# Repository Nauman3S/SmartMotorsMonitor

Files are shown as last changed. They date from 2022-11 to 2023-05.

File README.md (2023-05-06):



<!-- PROJECT LOGO -->
<br />
<div align="center">
  <a href="https://github.com/othneildrew/Best-README-Template">
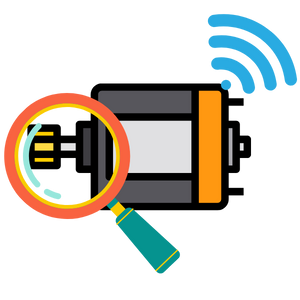
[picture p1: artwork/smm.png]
    
  </a>

  <h3 align="center">SmartMotorsMonitor</h3>

  <p align="center">
    Motors Monitoring System with different sensors.
    <br />
  </p>
</div>

---

<p align="center"> SmartMotorsMonitor
    <br> 
</p>

<!-- TABLE OF CONTENTS -->
<details>
  <summary>📝Table of Contents</summary>
  <ol>
    <li>
      <a href="#about-the-project">About The Project</a>
    </li>
    <li><a href="#getting_started">Getting Started</a></li>
    <li><a href="#circuit">Circuit</a></li>
    <li><a href="#architecture">Architecture</a></li>
    <li><a href="#usage">Usage</a></li>
    <li><a href="#webapp">WebApp</a></li>
    <li><a href="#smartphoneapp">SmartphoneApp</a></li>
    <li><a href="#built_using">Built Using</a></li>
    <li><a href="#authors">Authors</a></li>
  </ol>
</details>

<!-- ABOUT THE PROJECT -->
## 🧐 About 

This repo contains

- Firmware
- Circuit Diagram
- Detailed instructions

for Smart Motor Device Monitor.

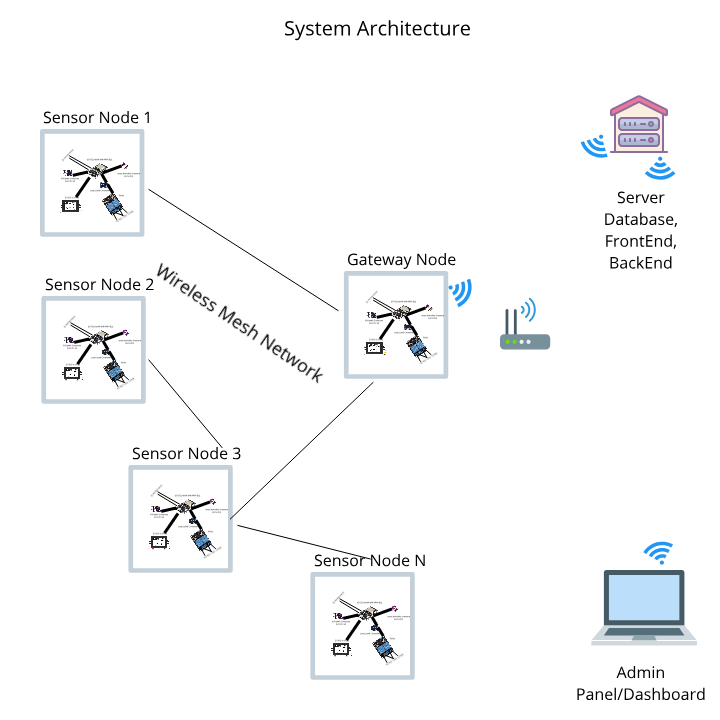
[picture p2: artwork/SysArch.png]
Architecture


<p align="right">(<a href="#readme-top">back to top</a>)</p>

## Getting Started 

These instructions will get you a copy of the project up and running on your system.

### Prerequisites

Things you need to install the FW.

```
- Arduino IDE
```

### Installing 

A step by step series that tell you how to get the Firmware and Backend running

#### ESP32 Configuration

You should have Arduino IDE Installed

  1.  Add ESP32 Board to your Arduino IDE
    1. In your Arduino IDE, go to File> Preferences
        Installing ESP32 Add-on in Arduino IDE Windows, Mac OS X, Linux open preferences
    2. Enter ```https://dl.espressif.com/dl/package_esp32_index.json``` 
        into the “Additional Board Manager URLs” field then, click the “OK” button:
        Note: if you already have the ESP32 boards URL, you can separate the URLs with a comma(each board will go to neaw line) as follows:
        ```https://dl.espressif.com/dl/package_esp32_index.json,\n http://arduino.esp8266.com/stable/package_esp8266com_index.json```

  2. Open the Boards Manager. Go to Tools > Board > Boards Manager…
  3. Search for ESP32 and press install button for the ESP32 by Espressif Systems“:
  4. That’s it. It should be installed after a few seconds.
  5.   In your Arduino sketchbook directory, create tools directory if it doesn't exist yet.
  6.  Unpack the tool into tools directory(present in libs/ESP32FS-1.0.zip) (the path will look like <home_dir>/Arduino/tools/ESP32FS/tool/esp32fs.jar).
  7.  Close and re-open the Arduino IDE.

  8.  Now copy the contents of the libs folder to the libraries directory of your Arduino
      1. If you are using windows, the libraries directory will be Documents/Arduino/libraries

##### ESP32 Node FW Uploading
  1.  Select ESP32 Dev Module from Tools->Board->ESP32
  2.  Select the correct port from Tools->Port
  3.  Open SensorNode.ino file.
  5.  Upload the Code to your ESP32 Dev Module.
  6.  Your ESP32-based SensorNode is now ready to be used.

##### ESP32 Gateway Node FW Uploading
  1.  Select ESP32 Dev Module from Tools->Board->ESP32
  2.  Select the correct port from Tools->Port
  3.  open GatewayNode.ino file,
  4.  Select Tools > ESP32 Sketch Data Upload menu item. This should start uploading the files into ESP32 flash file system.
  5.  Upload the Code to your ESP32 Dev Module.
  6.  Your ESP32-based Gateway Node is now ready to be used.

<p align="right">(<a href="#readme-top">back to top</a>)</p>

## Circuit 

### ESP32 Dev Module Pinout

Follow the pinout diagram given below to connect different components to your board.

![LoraPinout](Circuit/ESP32-Pinout.jpg)

### Circuit Diagram for Smart Joystick

Here's the complete circuit diagram of the system.

![CircuitDiagram](Circuit/Circuit_bb.png)

### Components Connections

```http
Pin connection details
```

#### HWT906-TTL - IMU

```HWT906-TTL Connections with ESP32```

** Remove the HWT906-TTL case to see the connections.

| HWT906-TTL Pins | ESP32 Dev Module Pins| 
| :--- | :--- | 
| `SCL` | `D22` |
| `SDA` | `D21` |
| `VCC` | `5V` |
| `GND` | `GND` |

#### ADS1015 - ADC

```ADS1015 Connections with ESP32```

| ADS1015 Pins | ESP32 Dev Module Pins| 
| :--- | :--- | 
| `SCL` | `D22` |
| `SDA` | `D21` |
| `VCC` | `5V` |
| `GND` | `GND` |

#### Analog Input Pins

```Analog Input Pin Connected with ADS1115```

| Analog Input Pins | ADS1115 Pins| 
| :--- | :--- | 
| `A_IN1` | `A0` |
| `A_IN2` | `A1` |

#### Digital Input Pins

```Digital Input Pin Connections with ESP32```

| Digital Input Pins | ESP32 Dev Module Pins| 
| :--- | :--- | 
| `D_IN1` | `D5` |
| `D_IN2` | `D18` |

#### 4 Channel Relay Pins

```Relay Module Pin Connections with ESP32```

| Relay Module Pins | ESP32 Dev Module Pins| 
| :--- | :--- | 
| `IN1` | `D14` |
| `IN2` | `D27` |
| `IN3` | `D26` |
| `IN4` | `D25` |
| `GND` | `GND` |
| `VCC` | `5V` |

*The relay module is connected to esp32 via Logic Level Shifter*

#### Status RGB LED

```LED Connections```

| LED Pins | ESP32 Dev Module | 
| :--- | :--- | 
| `Anode` | `33 via 220Ω resistor` |
| `Cathode` | `GND` |
*33 is also connected to the internal LED of ESP32 Dev Module*

<p align="right">(<a href="#readme-top">back to top</a>)</p>

## 🔧 Mesh Architecture 

High level architecture of the Mesh network
![arch](artwork/arch.png)

<p align="right">(<a href="#readme-top">back to top</a>)</p>

## Usage 

```diff
! Ready for testing
```
Power on your Sensor Nodes.

### Gateway Node
1.  Power on your ESP32, it will present you with an AP named ```SmartMM``` (while ```SmartMM``` can be changed in the portal)
2.  Default captive portal password `12345678AP` which can be changed in captive portal.
3.  Connect to the ESP32 access point and open the web-browser and navigate to the link ```http://SmartMM.local/_ac```. This link will work on most of the operating systems but if your operating system is not allowing to open it, you may want to check the captive portal IP Address from the serial monitor and can use that IP address inplace of the above mentioned URL.
4.  The default access IP Address is ```http://192.168.4.1/_ac```
5.  You will be presented with a main dashboard as shown below(based on your device)
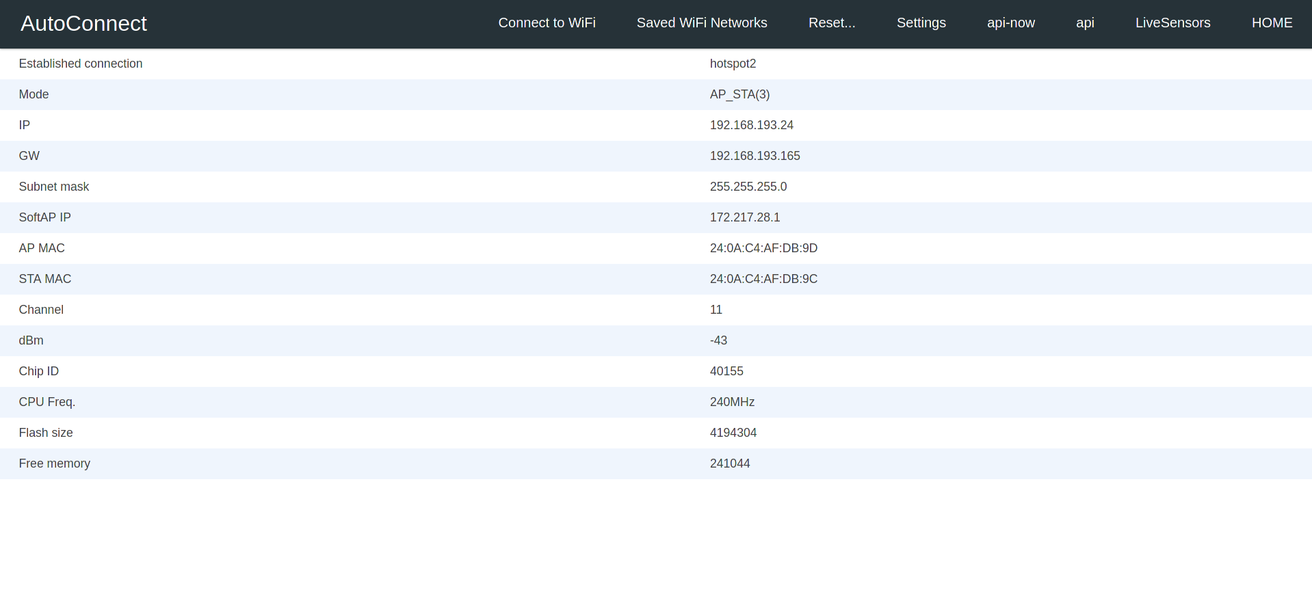
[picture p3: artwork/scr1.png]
SCR1
   

5.  Once connected to a WiFi network, you can again access the captive portal using same URL or the IP Address from the Serial monitor.
6.  The data is published to the MQTT Topic ```SmartMM/{hostname}``` while the hostname is the one which you can define in Settings page of the captive portal.

### Changing Timezone
```diff
+ Only for developers
```
1.  Open Settings tab
2.  Enter timezone string from https://en.wikipedia.org/wiki/List_of_tz_database_time_zones 'TZ database name' column.
3.  Click Save&Start

### API Endpoints and HTML URLS(for Gateway Node)

```API Endpoints```

| Endpoint | Description | 
| :--- | :--- | 
| `/api-now` | `API: live sensor readings in JSON format` |
| `/api` | `API: sensors data in JSON format` |
| `/LiveSensors` | `HTML PAGE: Live Sensor Data` |
| `/data` | `HTML PAGE: Historical Sensor Data` | 
| `/mqtt_settings` | `HTML PAGE: Settings. Default username: AP Name, Default Password: admin` | 
| `/_ac` | `HTML PAGE: Main Captive portal page` | 
| `/` | `HTML PAGE: Historical Sensor Data` | 

1.  **Connect to WiFi** tab allows searching of nearby WiFi APs and adding them to the ESP32.
   ![SCR3](artwork/scr3.png)
2.  **Saved WiFi Networks** tab allows connecting to the saved access points.
   ![SCR4](artwork/scr4.png)
3.  **Reset...** tab allows reseting of the device to factory settings.
    ![SCR5](artwork/scr5.png)
4.  **Settings** tab contains settings related to MQTT and sensors.
    ![SCR6](artwork/scr6.png)
5. **HOME** tab shows sensor data acquired live.

<p align="right">(<a href="#readme-top">back to top</a>)</p>

## Web App 
```diff
+ For future use
```
[Dashboard Link: ]()

You can access the webapp with following test acccount credentials

*   Email Address: `test@test.com`
*   Password: `test`

### Dashboard Screenshots

<p align="right">(<a href="#readme-top">back to top</a>)</p>

## Smartphone App 
```diff
+ For future use
```
[Smartphone App Link: ]()

You can access the Smartphone app with following test acccount credentials

*   Email Address: `test@test.com`
*   Password: `test`

### Smartphone App Screenshots

```diff
+ For future use.
```

<p align="right">(<a href="#readme-top">back to top</a>)</p>

## List of Components 
```diff
+ For future use; not a comprehensive list
```
Following components are used to make this project

1.  [ESP32 Dev Kit Module](https://www.amazon.ca/Robojax-Development-Bluetooth-Ultra-Low-Consumption/dp/B07PWGT83P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)

2. [Micro USB Cable](https://www.amazon.com/Android-Charger-sweguard-Charging-Phone-Grey/dp/B09MT18H3J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)

3. [Compass-IMU9250](https://www.amazon.ca/MPU-9250-MPU9250-Acceleration-Gyroscope-Compass/dp/B07T8J3WCX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)

4. [ADS1015](https://www.amazon.com/ADS1015-Ultra-Compact-12-Precision-Module-Development/dp/B07V85ZQBN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)

5. [DC Buck Converter](https://www.amazon.ca/Converter-Waterproof-Voltage-Reducer-Electronics/dp/B08YXHR5GY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)

6. [4 Channel Relay Module](https://www.amazon.ca/ELEGOO-Channel-Optocoupler-Arduino-Raspberry/dp/B06XCKQ1M9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)

7. [Bi-Directional Logic Level Shifter](https://www.amazon.ca/Channel-Logic-Converter-Bidirectional-Module/dp/B07GRL18G9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)

8. [Jumper Wires](https://www.amazon.com/EDGELEC-Breadboard-Optional-Assorted-Multicolored/dp/B07GD2BWPY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)

<p align="right">(<a href="#readme-top">back to top</a>)</p>

## ⛏️ Built Using 

- [Arduino](https://www.arduino.cc/) - Embedded Framework and IDE - For Sensor Node Design

<p align="right">(<a href="#readme-top">back to top</a>)</p>

## 📹 Demo Videos 
```diff
+ For future use
```
<!-- -   [Device Demo Video]() - Smart Joysticks Device Demo Video -->

<p align="right">(<a href="#readme-top">back to top</a>)</p>

## ✍️ Authors 

- [@Nauman3S](https://github.com/Nauman3S) - Development and Deployment

<p align="right">(<a href="#readme-top">back to top</a>)</p>

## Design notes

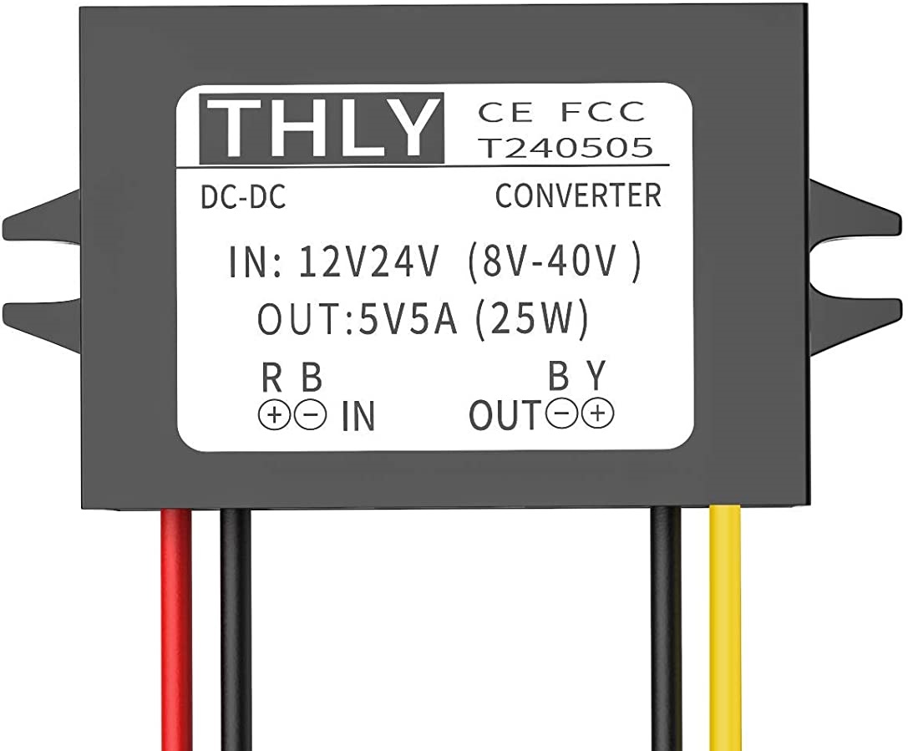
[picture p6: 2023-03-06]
Circuit/conv.jpg

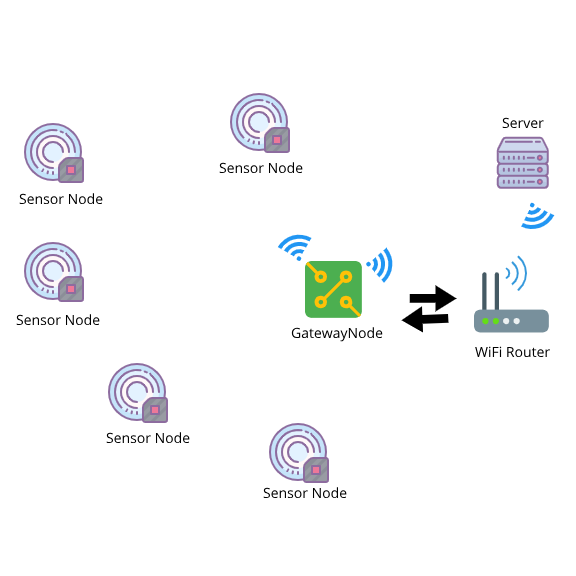
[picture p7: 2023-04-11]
artwork/arch.png

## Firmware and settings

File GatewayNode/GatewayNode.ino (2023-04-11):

#include "consts.h"
#include "digital_input_handler.h"
#include "ads_handler.h"
#include "relay_handler.h"
#include "mpu9250_handler.h"
#include "headers.h" //all misc. headers and functions
#include "esp32InternalTime.h"
#include "MQTTFuncs.h" //MQTT related functions
#include "webApp.h"    //Captive Portal webpages
#include <FS.h>        //ESP32 File System
#include "wifi_mesh_handler.h"


const long interval = 1000 * 60 * 5;        // Interval at which to read sensors//5 mintues
Neotimer dataAcqTimer = Neotimer(interval); // Set timer's preset
Neotimer sensorsDataTimer = Neotimer(1000); // Set timer's preset

IPAddress ipV(192, 168, 4, 1);
String loadParams(AutoConnectAux &aux, PageArgument &args) // function to load saved settings
{
    (void)(args);
    File param = FlashFS.open(PARAM_FILE, "r");
    String v1 = "0";
    String v2 = "0";
    String v3 = "0";
    String v4 = "0";
    String v5 = "0";

    if (param)
    {
        Serial.println("load params func");
        aux.loadElement(param);
        Serial.println(param);
        // Serial.println(args);

        AutoConnectText &D1ValueElm = aux["D_IN1"].as<AutoConnectText>();
        AutoConnectText &D2ValueElm = aux["D_IN2"].as<AutoConnectText>();
        AutoConnectText &A1ValueElm = aux["A_IN1"].as<AutoConnectText>();
        AutoConnectText &A2ValueElm = aux["A_IN2"].as<AutoConnectText>();
        AutoConnectText &IMUValueElm = aux["IMU"].as<AutoConnectText>();

        // vibSValueElm.value="VibS:91122";#

        v1 = String(D1ValueElm.value);
        v2 = String(D2ValueElm.value);
        v3 = String(A1ValueElm.value);
        v4 = String(A2ValueElm.value);
        v5 = String(IMUValueElm.value);

        if (v1.length() > 0)
        {
        }

        D1ValueElm.value = String("Digital Input 1: ") + getDigitalInputState(D_IN1);
        D2ValueElm.value = String("Digital Input 2: ") + getDigitalInputState(D_IN2);
        A1ValueElm.value = String("Analog Input 1: ") + getADS1115Values(A_IN1);
        A2ValueElm.value = String("Analog Input 2: ") + getADS1115Values(A_IN2);
        IMUValueElm.value = String("IMU(AX,AY,AZ,GX,GY,GZ,MX,MY,MZ,T): ") + getMPU9250Values();

        // curSValueElm.value="CurS:7788";
        param.close();
    }
    else
        Serial.println(PARAM_FILE " open failed");
    return String("");
}

String saveParams(AutoConnectAux &aux, PageArgument &args) // save the settings
{
    serverName = args.arg("mqttserver"); // broker
    serverName.trim();

    channelId = args.arg("channelid");
    channelId.trim();

    userKey = args.arg("userkey"); // user name
    userKey.trim();

    apiKey = args.arg("apikey"); // password
    apiKey.trim();

    timezone = args.arg("timezone"); // timezone
    timezone.trim();

    apPass = args.arg("apPass"); // ap pass
    apPass.trim();

    settingsPass = args.arg("settingsPass"); // ap pass
    settingsPass.trim();

    hostName = args.arg("hostname");
    hostName.trim();

    // The entered value is owned by AutoConnectAux of /mqtt_setting.
    // To retrieve the elements of /mqtt_setting, it is necessary to get
    // the AutoConnectAux object of /mqtt_setting.
    File param = FlashFS.open(PARAM_FILE, "w");
    portal.aux("/mqtt_setting")->saveElement(param, {"mqttserver", "channelid", "userkey", "apikey", "timezone", "hostname", "apPass", "settingsPass"});
    param.close();

    // Echo back saved parameters to AutoConnectAux page.
    AutoConnectText &echo = aux["parameters"].as<AutoConnectText>();
    echo.value = "Server: " + serverName + "<br>";
    echo.value += "Channel ID: " + channelId + "<br>";
    echo.value += "Timezone: " + timezone + "<br>";
    echo.value += "Username: " + userKey + "<br>";
    echo.value += "Password: " + apiKey + "<br>";
    echo.value += "ESP host name: " + hostName + "<br>";
    echo.value += "AP Password: " + apPass + "<br>";
    echo.value += "Settings Page Password: " + settingsPass + "<br>";
    mqttPublish("SmartMM/dev/config", String("tz;") + timezone); // publish timezone info
    return String("");
}
bool loadAux(const String auxName) // load defaults from data/*.json
{
    bool rc = false;
    Serial.println("load aux func");
    String fn = auxName + ".json";
    File fs = FlashFS.open(fn.c_str(), "r");
    if (fs)
    {
        rc = portal.load(fs);
        fs.close();
    }
    else
        Serial.println("Filesystem open failed: " + fn);
    return rc;
}
uint8_t inAP = 0;
bool whileCP()
{

    if (inAP == 0)
    {
        ledState(AP_MODE);
        inAP = 1;
    }
    // Serial.println("AP MODE");

    loopLEDHandler();
}

void setup() // main setup functions
{
    Serial.begin(115200);
    delay(1000);
    setupDigitalInputs();
    setupMPU9250();
    setupADS1115();
    setupRelays();
    setRelay(RELAY1, 0);
    setRelay(RELAY2, 0);
    setRelay(RELAY3, 0);
    setRelay(RELAY4, 0);

    if (!MDNS.begin("SmartMM")) // starting mdns so that user can access webpage using url `esp32.local`(will not work on all devices)
    {
        Serial.println("Error setting up MDNS responder!");
        while (1)
        {
            delay(1000);
        }
    }
#if defined(ARDUINO_ARCH_ESP8266)
    FlashFS.begin();
#elif defined(ARDUINO_ARCH_ESP32)
    FlashFS.begin(true);
#endif
    loadAux(AUX_MQTTSETTING);
    loadAux(AUX_MQTTSAVE);
    AutoConnectAux *setting = portal.aux(AUX_MQTTSETTING);
    if (setting) // get all the settings parameters from setting page on esp32 boot
    {
        Serial.println("Setting loaded");
        PageArgument args;
        AutoConnectAux &mqtt_setting = *setting;
        loadParams(mqtt_setting, args);
        AutoConnectInput &hostnameElm = mqtt_setting["hostname"].as<AutoConnectInput>();
        AutoConnectInput &apPassElm = mqtt_setting["apPass"].as<AutoConnectInput>();
        AutoConnectInput &serverNameElm = mqtt_setting["mqttserver"].as<AutoConnectInput>();
        AutoConnectInput &channelidElm = mqtt_setting["channelid"].as<AutoConnectInput>();
        AutoConnectInput &userkeyElm = mqtt_setting["userkey"].as<AutoConnectInput>();
        AutoConnectInput &apikeyElm = mqtt_setting["apikey"].as<AutoConnectInput>();
        AutoConnectInput &settingsPassElm = mqtt_setting["settingsPass"].as<AutoConnectInput>();
        // vibSValueElm.value="VibS:11";
        serverName = String(serverNameElm.value);
        channelId = String(channelidElm.value);
        userKey = String(userkeyElm.value);
        apiKey = String(apikeyElm.value);
        hostName = String(hostnameElm.value);
        apPass = String(apPassElm.value);
        settingsPass = String(settingsPassElm.value);
        if (hostnameElm.value.length())
        {
            // hostName=hostName+ String("-") + String(GET_CHIPID(), HEX);
            //;
            // portal.config(hostName.c_str(), apPass.c_str());
            //  portal.config(hostName.c_str(), "123456789AP");
            config.apid = hostName; // hostnameElm.value+ "-" + String(GET_CHIPID(), HEX);
            config.password = apPass;
            config.psk = apPass;
            // portal.config(hostName.c_str(), "123456789AP");
            Serial.println("(from hostELM) hostname set to " + hostName);
        }
        else
        {

            // hostName = String("OEE");;
            // portal.config(hostName.c_str(), "123456789AP");
            config.apid = hostName; // hostnameElm.value+ "-" + String(GET_CHIPID(), HEX);
            config.password = apPass;
            config.psk = apPass;
            // config.hostName = hostName;//hostnameElm.value+ "-" + String(GET_CHIPID(), HEX);
            //  portal.config(hostName.c_str(), "123456789AP");
            Serial.println("hostname set to " + hostName);
        }
        config.homeUri = "/_ac";
        config.apip = ipV;

        portal.on(AUX_MQTTSETTING, loadParams);
        portal.on(AUX_MQTTSAVE, saveParams);
    }
    else
    {
        Serial.println("aux. load error");
    }
    // config.homeUri = "/_ac";
    config.apip = ipV;
    config.autoReconnect = true;
    config.reconnectInterval = 1;
    Serial.print("AP: ");
    Serial.println(hostName);
    Serial.print("Password: ");
    Serial.println(apPass);
    config.title = "Smart Joystick"; // set title of webapp

    // add different tabs on homepage
    portal.append("/api-now", "api-now");
    portal.append("/api", "api");
    portal.append("/LiveSensors", "LiveSensors");
    portal.append("/data", "DataTable");
    portal.disableMenu(AC_MENUITEM_DISCONNECT);
    server.on("/", handleRoot);
    server.on("/api-now", cmotsValues);
    server.on("/api", api);
    server.on("/LiveSensors", live);
    server.on("/data", dataTable);
    // Starts user web site included the AutoConnect portal.

    config.auth = AC_AUTH_DIGEST;
    config.authScope = AC_AUTHSCOPE_PARTIAL;
    config.username = hostName;
    config.password = settingsPass;

    portal.config(config);
    portal.whileCaptivePortal(whileCP);
    portal.onDetect(atDetect);
    portal.load(FPSTR(PAGE_AUTH));
    if (portal.begin())
    {
        Serial.println("Started, IP:" + WiFi.localIP().toString());
        ledState(AP_MODE);
    }
    else
    {
        Serial.println("Connection failed.");
        while (true)
        {
            yield();
            delay(100);
        }
    }

    MDNS.addService("http", "tcp", 80);
    setupMeshGateway();// no mesh without internet connectivity
    mqttConnect(); // start mqtt
}
String latestInputValues = "";
String latestIMUValues = "";
void loop()
{
    server.handleClient();
    portal.handleRequest();
    loopLEDHandler();

    if (millis() - lastPub > updateInterval) // publish data to mqtt server
    {
        latestInputValues =
            getDigitalInputState(D_IN1) + String(";") + getDigitalInputState(D_IN2) + String(";") + getADS1115Values(A_IN1) + String(";") +
            getADS1115Values(A_IN2);
        latestIMUValues = getMPU9250Values();
        mqttPublish("SmartMM/" + String(hostName) + String("/inputs"), getTimestamp() + String(";") + latestInputValues); // publish data to mqtt broker
        mqttPublish("SmartMM/" + String(hostName) + String("/imu"), getTimestamp() + String(";") + latestIMUValues);      // publish data to mqtt broker
        Serial.println(latestInputValues);
        Serial.println(latestIMUValues);

        ledState(ACTIVE_MODE);

        lastPub = millis();
    }
    if (!mqttClient.connected())
    {
        reconnect();
    }
    mqttClient.loop();
    meshGatewayLoop();
    if (WiFi.status() == WL_IDLE_STATUS)
    {
        ledState(IDLE_MODE);
        ESP.restart();

        delay(1000);
    }
}

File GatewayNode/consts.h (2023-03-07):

#define WIFI_SSID 0
#define WIFI_PASSWORD 1

#define A_IN1 2
#define A_IN2 3

#define D_IN1_PIN 5
#define D_IN2_PIN 18

#define D_IN1 4
#define D_IN2 5

#define RELAY_PIN1 14
#define RELAY_PIN2 27
#define RELAY_PIN3 26
#define RELAY_PIN4 25

#define RELAY1 6
#define RELAY2 7
#define RELAY3 8
#define RELAY4 9

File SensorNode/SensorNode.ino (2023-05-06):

// Sensor Node
#include "consts.h"
#include "headers.h"
#include "digital_input_handler.h"
#include "ads_handler.h"
#include "relay_handler.h"
#include "mpu9250_handler.h"
#include "esp32InternalTime.h"

// Prototypes
void sendMessage();
void receivedCallback(uint32_t from, String &msg);
void newConnectionCallback(uint32_t nodeId);
void changedConnectionCallback();
void nodeTimeAdjustedCallback(int32_t offset);
void delayReceivedCallback(uint32_t from, int32_t delay);

Scheduler userScheduler; // to control your personal task
painlessMesh mesh;

bool calc_delay = false;
SimpleList<uint32_t> nodes;

void sendMessage();                                                // Prototype
Task taskSendMessage(TASK_SECOND * 1, TASK_FOREVER, &sendMessage); // start with a one second interval

// Task to blink the number of nodes
Task blinkNoNodes;
bool onFlag = false;
String TrackerID = "";

String latestInputValues = "";
String latestIMUValues = "";
void setup()
{
    Serial.begin(115200);
    TrackerID = ss.getMACAddress();
    Serial.print("TrackerID: ");
    Serial.println(TrackerID);
    pinMode(BUILTIN_LED, OUTPUT);
    setupDigitalInputs();
    setupMPU9250();
    setupADS1115();
    setupRelays();
    setRelay(RELAY1, 0);
    setRelay(RELAY2, 0);
    setRelay(RELAY3, 0);
    setRelay(RELAY4, 0);

    mesh.setDebugMsgTypes(ERROR | DEBUG); // set before init() so that you can see error messages

    mesh.init(MESH_SSID, MESH_PASSWORD, &userScheduler, MESH_PORT);
    mesh.onReceive(&receivedCallback);
    mesh.onNewConnection(&newConnectionCallback);
    mesh.onChangedConnections(&changedConnectionCallback);
    mesh.onNodeTimeAdjusted(&nodeTimeAdjustedCallback);
    mesh.onNodeDelayReceived(&delayReceivedCallback);
    mesh.setContainsRoot(true);

    userScheduler.addTask(taskSendMessage);
    taskSendMessage.enable();

    blinkNoNodes.set(BLINK_PERIOD, (mesh.getNodeList().size() + 1) * 2, []()
                     {
      // If on, switch off, else switch on
      if (onFlag)
        onFlag = false;
      else
        onFlag = true;
      blinkNoNodes.delay(BLINK_DURATION);

      if (blinkNoNodes.isLastIteration()) {
        // Finished blinking. Reset task for next run 
        // blink number of nodes (including this node) times
        blinkNoNodes.setIterations((mesh.getNodeList().size() + 1) * 2);
        // Calculate delay based on current mesh time and BLINK_PERIOD
        // This results in blinks between nodes being synced
        blinkNoNodes.enableDelayed(BLINK_PERIOD - 
            (mesh.getNodeTime() % (BLINK_PERIOD*1000))/1000);
      } });
    userScheduler.addTask(blinkNoNodes);
    blinkNoNodes.enable();

    randomSeed(analogRead(A0));
}

void loop()
{
    mesh.update();
    digitalWrite(BUILTIN_LED, !onFlag);
}

void sendMessage()
{
    latestInputValues =
        getDigitalInputState(D_IN1) + String(";") + getDigitalInputState(D_IN2) + String(";") + getADS1015Values(A_IN1) + String(";") +
        getADS1015Values(A_IN2);
    latestIMUValues = getMPU9250Values();
    String msg = "FRMID: " + TrackerID + String("__"); // FRMID=From ID
    msg += mesh.getNodeId();
    // msg += " myFreeMemory: " + String(ESP.getFreeHeap());
    msg += ";" + latestInputValues;
    msg += ";" + latestIMUValues;
    mesh.sendBroadcast(msg);

    if (calc_delay)
    {
        SimpleList<uint32_t>::iterator node = nodes.begin();
        while (node != nodes.end())
        {
            mesh.startDelayMeas(*node);
            node++;
        }
        calc_delay = false;
    }

    Serial.printf("Sending message: %s\n", msg.c_str());

    taskSendMessage.setInterval(random(TASK_SECOND * 4, TASK_SECOND * 5)); // between 4 and 5 seconds
}

void receivedCallback(uint32_t from, String &msg)
{
    Serial.printf("startHere: Received from %u msg=%s\n", from, msg.c_str());
}

void newConnectionCallback(uint32_t nodeId)
{
    // Reset blink task
    onFlag = false;
    blinkNoNodes.setIterations((mesh.getNodeList().size() + 1) * 2);
    blinkNoNodes.enableDelayed(BLINK_PERIOD - (mesh.getNodeTime() % (BLINK_PERIOD * 1000)) / 1000);

    Serial.printf("--> startHere: New Connection, nodeId = %u\n", nodeId);
    Serial.printf("--> startHere: New Connection, %s\n", mesh.subConnectionJson(true).c_str());
}

void changedConnectionCallback()
{
    Serial.printf("Changed connections\n");
    // Reset blink task
    onFlag = false;
    blinkNoNodes.setIterations((mesh.getNodeList().size() + 1) * 2);
    blinkNoNodes.enableDelayed(BLINK_PERIOD - (mesh.getNodeTime() % (BLINK_PERIOD * 1000)) / 1000);

    nodes = mesh.getNodeList();

    Serial.printf("Num nodes: %d\n", nodes.size());
    Serial.printf("Connection list:");

    SimpleList<uint32_t>::iterator node = nodes.begin();
    while (node != nodes.end())
    {
        Serial.printf(" %u", *node);
        node++;
    }
    Serial.println();
    calc_delay = true;
}

void nodeTimeAdjustedCallback(int32_t offset)
{
    Serial.printf("Adjusted time %u. Offset = %d\n", mesh.getNodeTime(), offset);
}

void delayReceivedCallback(uint32_t from, int32_t delay)
{
    Serial.printf("Delay to node %u is %d us\n", from, delay);
}

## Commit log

2022-11-27 added SmartJoystickTemplate
    [Circuit-btn.fzz, Circuit.fzz]
2022-11-27 updated Firmware, Circuit Diagram and readme.md
    [Circuit-btn.fzz, Circuit.fzz]
2022-11-28 updated README.md, Circuit diagram and Firmware
    [Circuit.fzz]
2022-11-28 udpated Circuit diagram and Firmware
    [Circuit.fzz]
2023-03-06 updated README, refactored Firmware
    [Circuit.fzz]
2023-04-11 updated Circuit diagram, added HWT906 in place of MPU9250, updated JU901 lib to reslove errors
    [Circuit.fzz]
2023-04-11 added sensor node mesh firmware, added gateway node template.
2023-05-06 Added MLD controlled in the Circuit diagram, updated README, updated code to handle the relays
    [Circuit.fzz]
2023-05-06 updated circuit diagram
2023-05-06 remvoed Circuit diagram
2023-05-06 updated Circuit_bb
2023-05-06 updated Circuit_bb, added ADS1015 to allow +/-24v input
    [Circuit.fzz]
2023-05-06 updated sensor node firmware and circuit diagram to use ADS1015
